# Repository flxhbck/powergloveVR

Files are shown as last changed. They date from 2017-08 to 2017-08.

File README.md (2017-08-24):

# PowergloveVR

Resources to modify the Powerglove to become compatible with the HTC Vive VR system. Requires a Vive tracker puck and an Arduino Due. 

This project was done at Teague Labs.

## Arduino
This code is written for the Arduino Due! The program reads the analog values of the bending sensors and communicates to the HTC Vive Tracker. The code performs “auto-calibration” on the sensor values and smoothes the values over time. The communication between the Arduino Due and the Vive tracker builds on the USB-Host Library extension by [matzmann666](https://github.com/matzman666/USBHost). Since only three analog values can be transmitted via the tracker, the middle and ring finger values are alternated over time.

## CAD
Printable and editable files for mounting the Vive tracker and Arduino Due on the Powerglove.

## Eagle
Arduino Due Shield for reading the analog bending sensors of the Powerglove. Includes battery charging module, two indicator LEDs, and a push-button. The folder also includes the image-file we used for etching.
This is a very quick and dirty design, so use it cautiously. When you look at the board design, you’ll see that some extra bridge-wires have to be soldered to the pads. The board works, but there are couple of missteps. Most importantly, the charger footprint is off.

## Unity
Example project with a rigged hand model that listens to the puck.

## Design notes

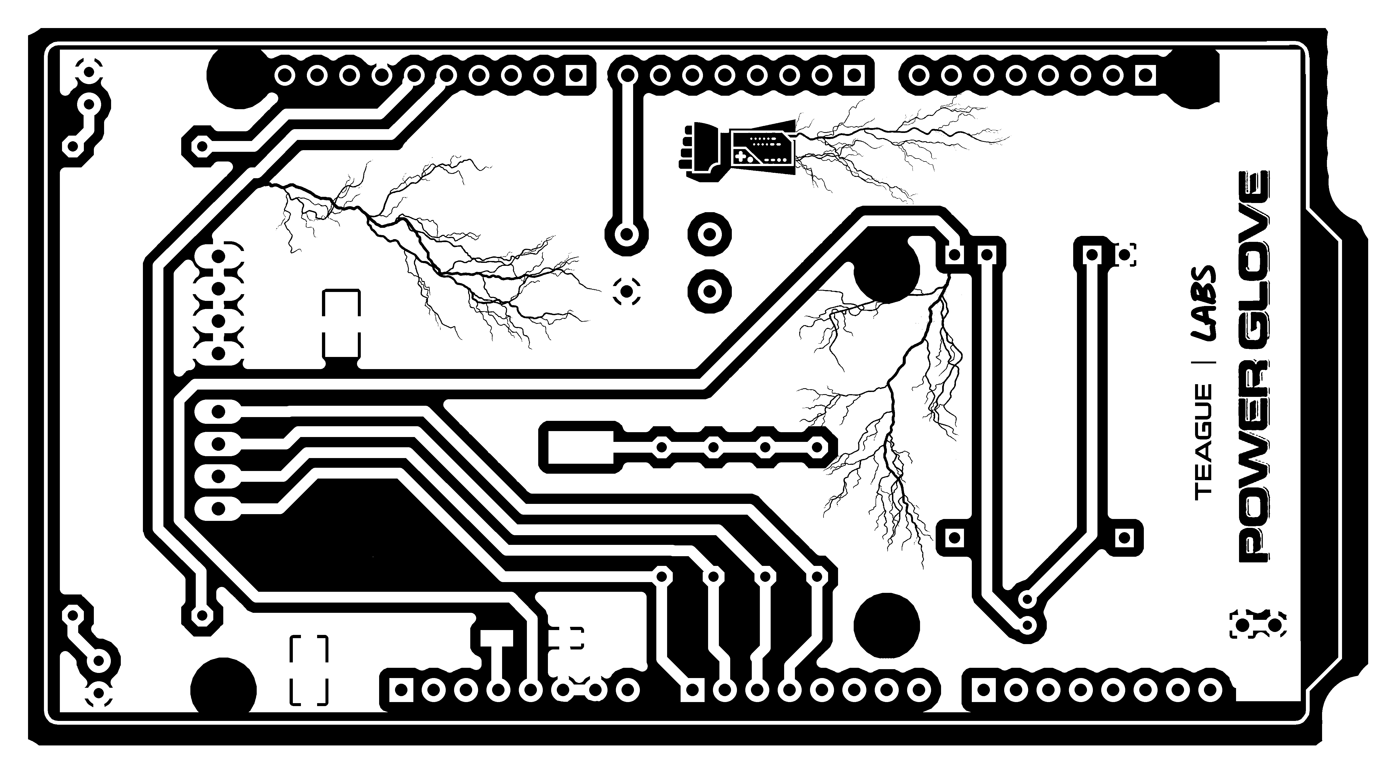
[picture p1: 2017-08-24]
eagle/powerglove_shield_design.png

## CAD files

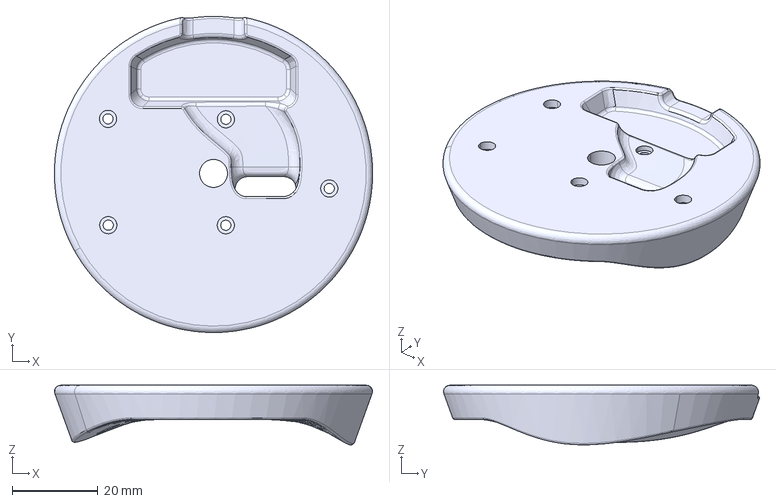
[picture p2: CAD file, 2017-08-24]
cad/PG_Puck_mount.stp
74.0 x 73.5 x 13.9 mm

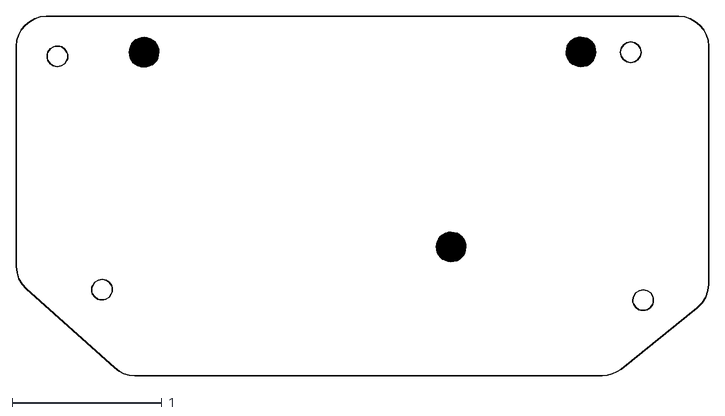
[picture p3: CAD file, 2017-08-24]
cad/power-glove-due-plate.dxf
4.62 x 2.40

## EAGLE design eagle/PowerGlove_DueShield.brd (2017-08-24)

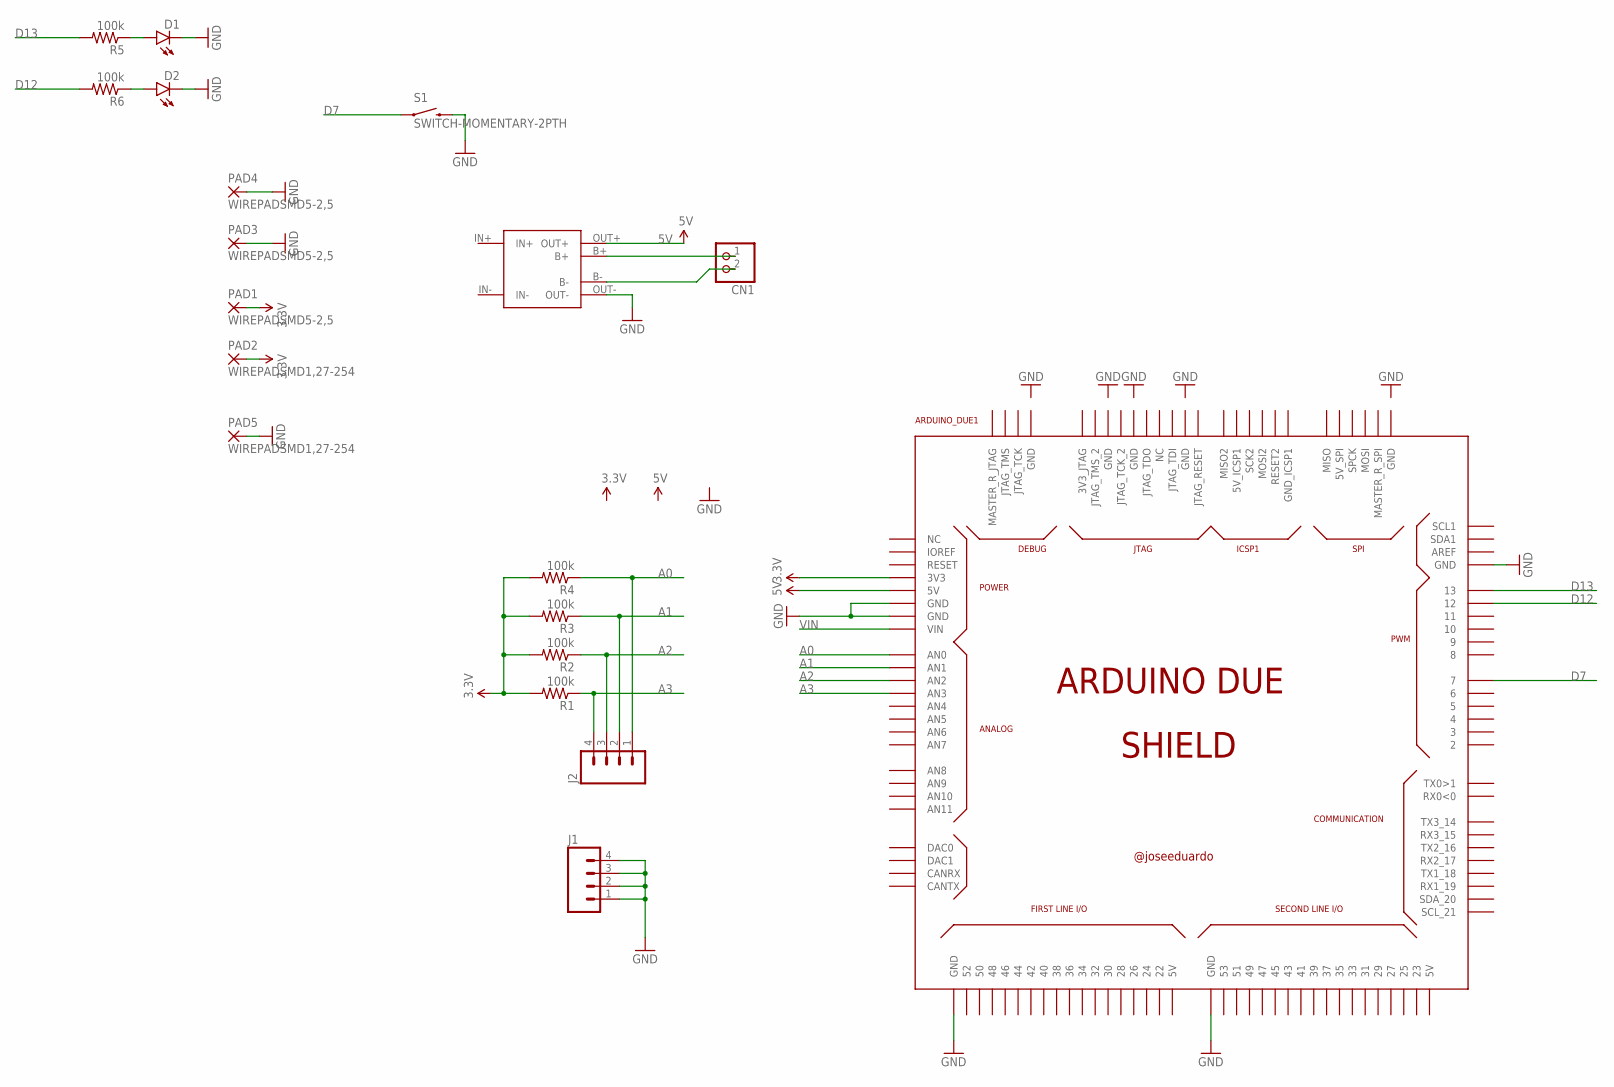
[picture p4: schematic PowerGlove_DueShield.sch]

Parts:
ARDUINO_DUE1: ARDUINO_DUE_SHIELD
CN1: JST_2PIN-THM-RA; JST-PH-2-THM-RA
D1, D2: LED3MM
J1, J2: M04LONGPADS; 1X04_LONGPADS
PAD1, PAD3, PAD4: WIREPADSMD5-2,5; 5-2,5
PAD2, PAD5: WIREPADSMD1,27-254; SMD1,27-2,54
R1, R2, R3, R4, R5, R6: 100k; 0207/10
S1: SWITCH-MOMENTARY-2PTH; TACTILE-PTH
U$1: TP4056-MODULE; TP4056-LITHIUM-PROTECTED-MODULE

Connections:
3.3V: ARDUINO_DUE1.3V3, PAD1.1, PAD2.1, R1.2, R2.2, R3.2, R4.2
5V: ARDUINO_DUE1.5V0 (5V), U$1.OUT+
A0: ARDUINO_DUE1.A0 (AN0), J2.1, R4.1
A1: ARDUINO_DUE1.A1 (AN1), J2.2, R3.1
A2: ARDUINO_DUE1.A2 (AN2), J2.3, R2.1
A3: ARDUINO_DUE1.A3 (AN3), J2.4, R1.1
B+: CN1.1 (2), U$1.B+
B-: CN1.2 (1), U$1.B-
D7: ARDUINO_DUE1.7, S1.1
D12: ARDUINO_DUE1.12, R6.2
D13: ARDUINO_DUE1.13, R5.2
GND: ARDUINO_DUE1.GND, ARDUINO_DUE1.GND_1 (GND), ARDUINO_DUE1.GND_2 (GND), ARDUINO_DUE1.GND_3 (GND), ARDUINO_DUE1.GND_4 (GND), D1.K (C), D2.K (C), J1.1, J1.2, J1.3, J1.4, PAD3.1, PAD4.1, PAD5.1, S1.3 (2), U$1.OUT-
IN+: U$1.IN+
IN-: U$1.IN-
unnamed: D1.A, R5.1
unnamed: D2.A, R6.1
VIN: ARDUINO_DUE1.VIN

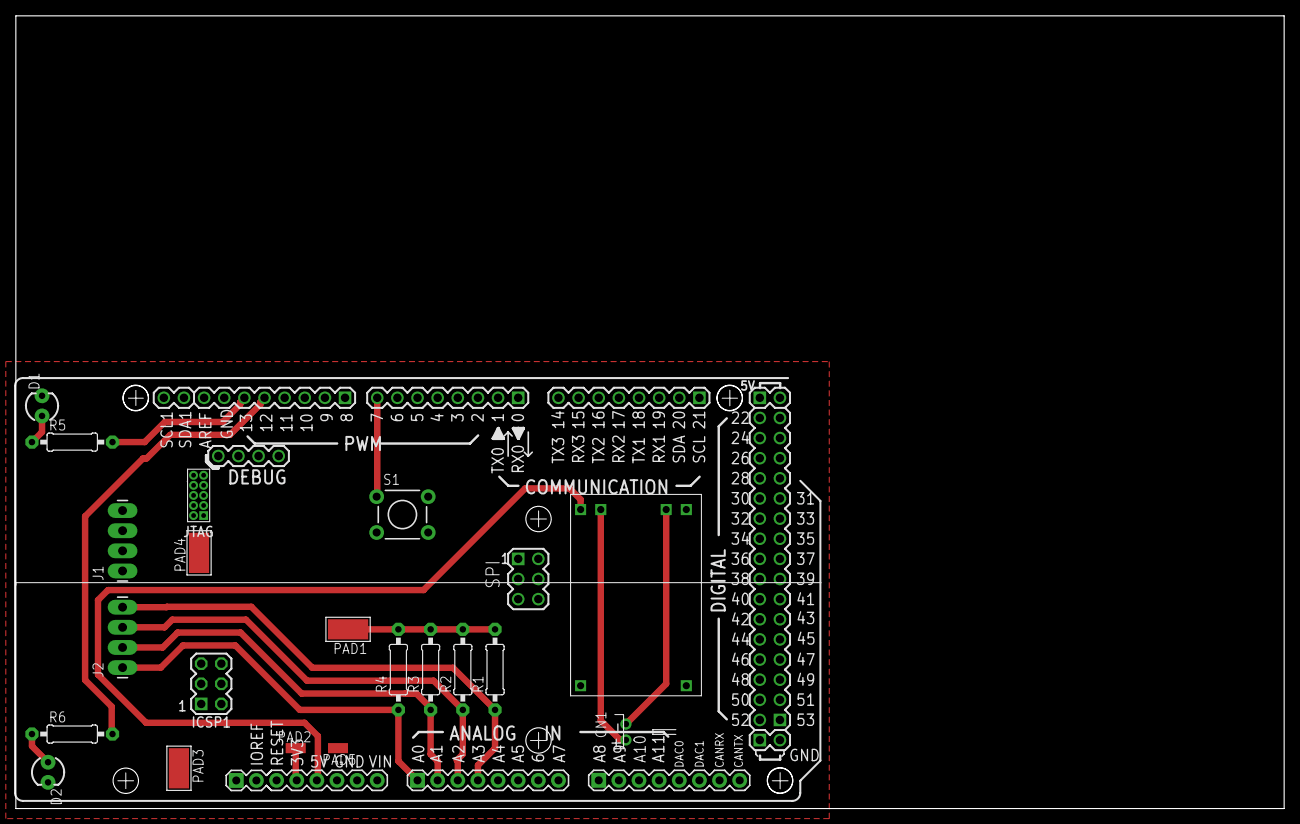
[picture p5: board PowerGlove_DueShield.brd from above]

Board: 2 copper layers, 160.0 x 100.0 mm, 19 parts (0 on the bottom side), 14 nets.

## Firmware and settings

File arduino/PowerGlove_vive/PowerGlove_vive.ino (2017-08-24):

// Require vive tracker controller library
#include <ViveTrackerController.h>


#DEFINE DEBUG 0

// Initialize USB Host Controller
USBHost usb;

// Attach vive tracker controller to USB
ViveTrackerController tracker(usb);

int minVal[] = {1023, 1023, 1023, 1023};
int maxVal[] = {0, 0, 0, 0};
int calibratedValue[] = {0, 0, 0, 0};
int oldVal[] = {0, 0, 0, 0};

bool toggle = true;




void setup() {
  // initialize serial communication at 9600 bits per second:
  if(DEBUG) Serial.begin(115200);
  if(DEBUG) Serial.println("Program started");
  delay(200);


  pinMode(7, INPUT_PULLUP);
  pinMode(13, OUTPUT);
  pinMode(12, OUTPUT);
  digitalWrite(13, LOW);
  digitalWrite(12, LOW);

  //init oldVals
  for (int i = 0; i < 4; i++) {
    oldVal[i] = analogRead(i);
  }

}


void loop() {
  // calibrate on button press
  if ( buttonPressed() ) {
    resetCalibration();
  }

  tracker.Task(); // Process usb and vive tracker controller tasks
  if (tracker.isConnected()) {
    digitalWrite(12, HIGH);

    // read and calibrate values
    for (int i = 0; i < 4; i++) {
      calibratedValue[i] = getCalibratedValue(smoothAnalogValue(i), i);
    }

    for (int i = 0; i < 4; i++) {
      if(DEBUG) Serial.print(calibratedValue[i]);
      if(DEBUG) Serial.print("\t");
    }
    if(DEBUG) Serial.println();

    uint8_t buttons = 0;
    int8_t trigger;
    
    if (toggle) {
      buttons = VIVETRACKER_BUTTON_GRIP;
      trigger = map(calibratedValue[2], 0, 1023,  0, 255); // middle finger
    } else {
      trigger = map(calibratedValue[3], 0, 1023,  0, 255); // ring finger
    }
    toggle = !toggle;

    int16_t padX = map(calibratedValue[1], 0, 1023,  0, 32767); // index finger
    int16_t padY = map(calibratedValue[0], 0, 1023,  0, 32767); //thumb

    uint16_t batteryLevel = 0;
    tracker.setTrackerStatus(buttons, padX, padY, trigger, batteryLevel);

  } else {
    digitalWrite(12, LOW);
  }

  delay(10); // According to HTC's documentation the interval to send data should be at least 10 ms.
}


float getVoltage(int analogValue) {
  return analogValue * (3.3 / 1023.0);
  //return analogValue;
}

bool buttonPressed() {
  return !digitalRead(7);
}

void resetCalibration() {
  digitalWrite(13, HIGH);

  //reset calibration values
  for (int i = 0; i < 4; i++) {
    minVal[i] = 1023;
    maxVal[i] = 0;
  }

  digitalWrite(13, LOW);
}

int getCalibratedValue(int val, int index) {
  if (val < minVal[index]) minVal[index] = val;
  if (val > maxVal[index]) maxVal[index] = val;
  return map(val, minVal[index], maxVal[index], 0, 1023);
  //return ((float)(val - minVal[index])) / ((float)(maxVal[index] - minVal[index]));
}

int smoothAnalogValue(int index) {
  oldVal[index] = round( ((float)oldVal[index]) * 0.5f + ((float)analogRead(index)) * 0.5f);
  return oldVal[index];
}

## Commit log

2017-08-24 add eagle and arduino files.
    [PowerGlove_DueShield.brd, PowerGlove_DueShield.sch]
2017-08-24 add CAD files
    [PG_Puck_mount.stp, power-glove-due-plate.dxf]

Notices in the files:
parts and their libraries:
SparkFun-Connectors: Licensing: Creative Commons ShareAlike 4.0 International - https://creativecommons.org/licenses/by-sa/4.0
